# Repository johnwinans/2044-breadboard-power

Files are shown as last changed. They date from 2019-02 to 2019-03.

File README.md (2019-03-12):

# 2044-breadboard-power V3
Power supply for a breadboard.

These are the source files for a KiCad project featured in a tutorial here:

https://www.youtube.com/playlist?list=PL3by7evD3F51fKkyrUbH-PCdwPCWc9F8a

If you want to make one of these for yourself you can use this design as
it is or and alter it and make it better.  

If you just want one, see the PDF file for the digikey order IDs of the parts
and here is a place where you can order 3 of these (bare boards) for $6.30 
including shipping (I don't get a penny of that by the way.  I just think it 
is a decent deal):

https://oshpark.com/shared_projects/D6qLABBx

Here are some images of the release V3 (USB-powered) board:

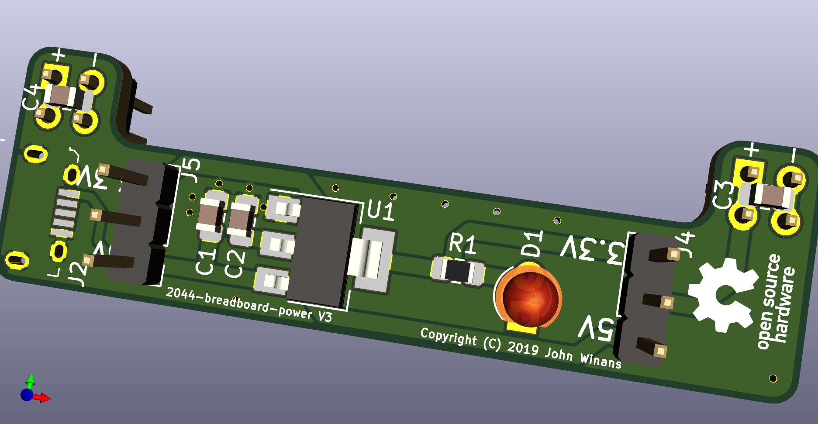
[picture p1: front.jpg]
V2 Front


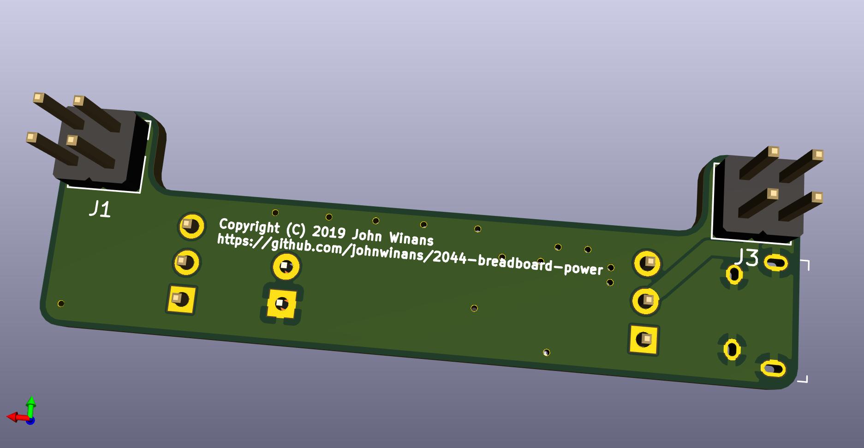
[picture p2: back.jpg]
V2 Back


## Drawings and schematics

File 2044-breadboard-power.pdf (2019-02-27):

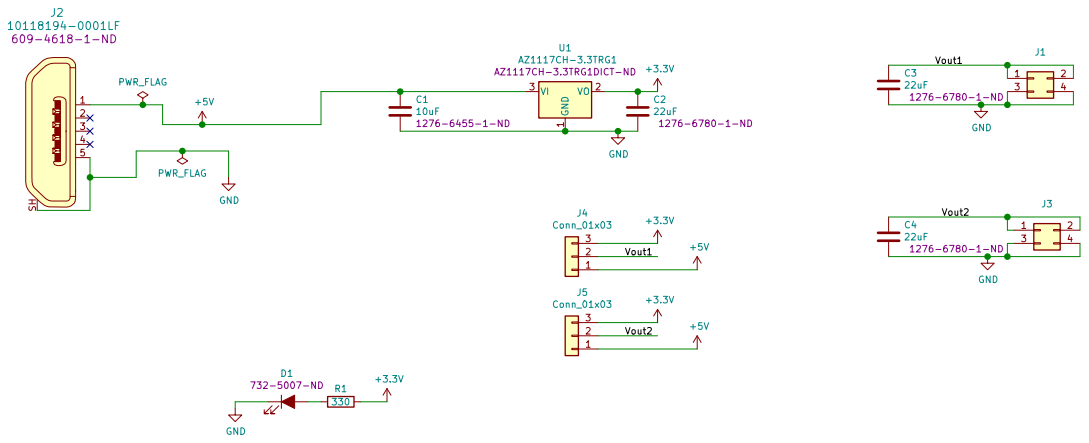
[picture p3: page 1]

File: 2044-breadboard-power.sch Sheet: / https://github.com/johnwinans/2044-breadboard-power GND

Copyright (C) 2019 John Winans This documentation describes Open Hardware and is licensed under the CERN OHL v. 1.2. You may redistribute and modify

this documentation under the terms of the CERN OHL v.1.2. (http://ohwr.org/cernohl). This documentation is distributed WITHOUT ANY EXPRESS OR IMPLIED WARRANTY, INCLUDING OF MERCHANTABILITY, SATISFACTORY QUALITY AND FITNESS FOR A PARTICULAR PURPOSE. Please see the CERN OHL v.1.2 for applicable conditions

If you chose to manufacture products based on this design, please notify me (see license section 4.2) via john@winans.org

Id: 1/1 Title: Breadboard Power Supply

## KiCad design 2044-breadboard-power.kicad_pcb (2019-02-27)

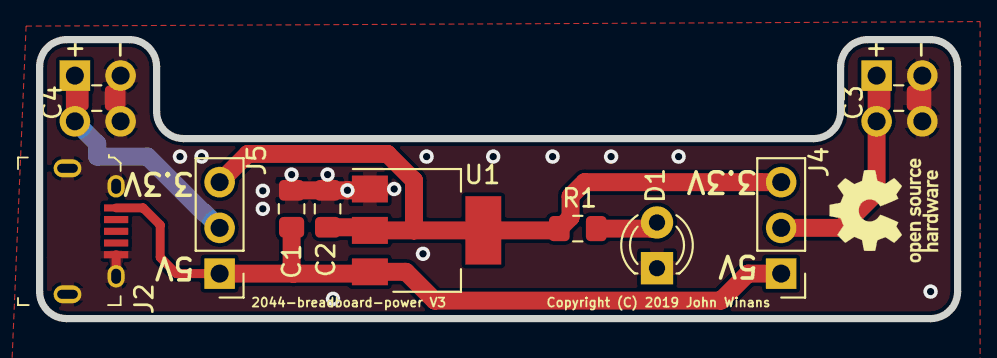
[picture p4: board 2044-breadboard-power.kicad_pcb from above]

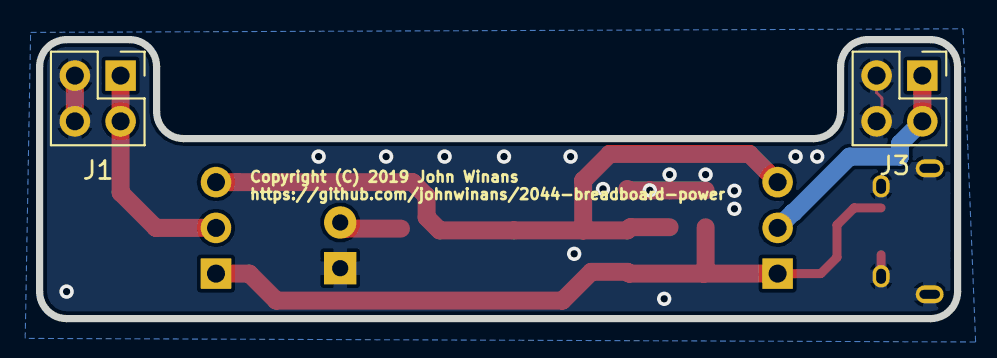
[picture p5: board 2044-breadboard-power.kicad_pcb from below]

Board: 2 copper layers, 51.0 x 15.5 mm, 12 parts (2 on the bottom side), 6 nets.

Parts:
C1: 10uF; C_0805_2012Metric_Pad1.15x1.40mm_HandSolder
C2, C3, C4: 22uF; C_0805_2012Metric_Pad1.15x1.40mm_HandSolder
D1: LED_ALT; LED_D3.0mm
J1, J3: Conn_02x02_Odd_Even; PinHeader_2x02_P2.54mm_Vertical
J2: 10118194-0001LF; USB_Micro_B_Female_10118194-0001LF
J4, J5: Conn_01x03; PinHeader_1x03_P2.54mm_Vertical
R1: 330; R_0805_2012Metric_Pad1.15x1.40mm_HandSolder
U1: AZ1117CH-3.3TRG1; SOT-223-3_TabPin2

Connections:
+3V3: C2.1, J4.3, J5.3, R1.1, U1.2
+5V: C1.1, J2.1, J4.1, J5.1, U1.3
/Vout1: C3.1, J1.1, J1.2, J4.2
/Vout2: C4.1, J3.1, J3.2, J5.2
GND: C1.2, C2.2, C3.2, C4.2, D1.1, J1.3, J1.4, J2.5, J2.SH, J3.3, J3.4, U1.1
unnamed: D1.2, R1.2

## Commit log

2019-02-10 Initial project import.
    [2044-breadboard-power.kicad_pcb, 2044-breadboard-power.sch]
2019-02-11 Change power connector to USB & remove 5V reg.
    [2044-breadboard-power.kicad_pcb, 2044-breadboard-power.sch]
2019-02-13 Fix typo in solder mask width value.
    [2044-breadboard-power.kicad_pcb]
2019-02-13 Added images of the PCB.
2019-02-21 Add digikey number for J2.
    [2044-breadboard-power.sch]
2019-02-25 Fixed the wrong Digikey part number for J2.
    [2044-breadboard-power.sch]
2019-02-27 Add ground on the output headers.
    [2044-breadboard-power.kicad_pcb, 2044-breadboard-power.sch]
2019-03-12 Board received and tested OK. Removed warning.
